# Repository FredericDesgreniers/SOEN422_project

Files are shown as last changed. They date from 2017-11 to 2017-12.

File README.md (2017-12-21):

# Force Test - SOEN422 Group Project
Our plan for this project to to build a force test system which is intended to be used for boxers/kickboxers to gauge the force the hit the bag with; see the [project proposal](#https://github.com/FredericDesgreniers/SOEN422_project/blob/master/Docs/Proposal.md) for more details.

### Table of Contents
1. [Contributors](#Contributors)

## Contributors - Team A
**Name** | **ID**
:--:|---
Christopher McArthur | `40004257`
Frederic Desgreniers | `40016777`

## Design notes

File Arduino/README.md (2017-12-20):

# Arduino

## Attributions
* [HX711 Library](https://github.com/bogde/HX711)
* [HX711 Tutorial](http://www.instructables.com/id/How-to-Interface-HX711-Balance-Module-With-Load-Ce/) // using same model
* [Complete Guide](https://circuits4you.com/2016/11/25/hx711-arduino-load-cell/) // using same model
* [Loadcell Technical Information](https://www.phidgets.com/docs/Load_Cell_Primer#Single-Point_Load_Cells)
* [How to wire four wheatestone bridge load sensors](https://electronics.stackexchange.com/questions/111887/load-cells-in-series)
* [HX711 datasheet](https://www.mouser.com/ds/2/813/hx711_english-1022875.pdf)

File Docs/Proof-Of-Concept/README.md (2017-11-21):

# Proof of Concept - Team Cerberus
In this stage of the project we set out to build a small test setup using the hardware obtained. This would allow us to build the Web UI and communication components congruently with the engineering of the full scale device and proide the necessary knowledge to build a full system.

> To best view this document, use the [link](https://github.com/FredericDesgreniers/SOEN422_project/blob/master/Docs/Proof-Of-Concept/README.md) provided.

### Table of Contents
1. [Contributors](#Contributors)
2. [Test Unit](#test-unit)
3. [Results](#results)
4. [Future Rquirements](#Future-Rquirements)
5. [Figures](#Figures)

## Contributors
**Name** | **ID**
:--:|---
Christopher McArthur | `40004257`
Frederic Desgreniers | `40016777`

## Test Unit
Using the Arduino Nano Rev3, an HX711 and a 10kg load cell we built a small scale to prove that we can be able to register the force applied to the strain gauge. See [figure 1](#figure-1) for reference. Determining how to correctly wire the load cell to the HX711 and connecting that to the Arduino possed several challenges as some resources used different wire layouts. The diagram below shows the correct layout: 

## Results
Using the [HX711 Library](https://github.com/bogde/HX711) and some sample code provided for the HX711 by [SparkFun](https://learn.sparkfun.com/tutorials/load-cell-amplifier-hx711-breakout-hookup-guide) we were able to successfully calibrate the scale to accurately weigh a 3 and 10 pouns weights.

## Future Rquirements
* [Combinator Board](http://www.robotshop.com/ca/en/load-sensor-combinator-v11.html)
* [50kg Load Cell](http://www.robotshop.com/ca/en/micro-load-cell-50-kg.html) X4 (Seriouly four)

The goal is to measure the force delivered with a punch (by a retired amature kickboxer). In order to do this we need to have load cells which will be able to capture that quantity of force. We have settled for 4 x 50kg load cells giving a total of 440lbs. These will make the engineering more simple compared to using other types of strain gauges. The proposed design will feature two circular plates that will be bolts to the load cells. The top plate will be half the diameter of the bottom plate. The direction of the load cells will be places in the center to register the force applied to the top plate. See [figure 2](#figure-2) and [figure 2](#figure-2) for a visual. The 4 x 50kg load cells will be connected with a combinator board which is required to have all four work as one which will then be connected to the HX711 and the Nano.

## Figures

### Figure 1


### Figure 2


### Figure 3


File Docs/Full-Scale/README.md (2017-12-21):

# Force Gauge - Team A
In this project we aimed to develop a force gauge which was capable of detecting the force applied from a human punch. This document outlines the goals of the project, the design of the system, and the final resulting prototype which was delivered.

> To best view this document, use this [link](https://github.com/FredericDesgreniers/SOEN422_project/blob/master/Docs/Full-Scale/README.md).

### Table of Contents
1. [Contributors](#contributors)
1. [Introduction](##force-gauge---team-a)
1. [Description](#description)
   1. [Name](#name)
   1. [Functionality](#functionality)
   1. [Performance](#performance)
   1. [Scope of Completion](#scope-of-completion)
1. [Hardware Design](#hardware-design)
   1. [System](#system)
   1. [Subsystems](#subsystems)
   1. [Intercommunication](#intercommunication)
1. [Software Design](#software-design)
   1. [System Design](#system-design)
   1. [Subsystems](#subsystems)
      1. [Arduino Functions](#arduino)
      1. [BeagleBone Functions](#beaglebone)
      1. [External Functions](#Web-Server)
   1. [System Software Communication](#system-software-communication)
1. [Development Software and Enviroments](#development-software)
1. [System Delivery](#system-delivery)
   1. [Initialisation](#system-initialisation)
   1. [Operation](#system-operation)
1. [Discussion](#discussion)
1. [Apendix](#apendix)

## Contributors
**Name** | **ID**
:--:|---
Christopher McArthur | `40004257`
Frederic Desgreniers | `40016777`

## Description
#### Name
This force gague system, called the **Punch O-Meter**, is designed to be placed into any punching bag and display live results of the forces being applied.

#### Functionality
The system would include a web server and with an internet connection allowing users to view the data from their computer or mobile device. This data is the _force_ currently applied to the bag which is being captured by a microcontroller of the force gauge(s) set up in the bag. 

#### Performance
It is designed to capture the force from various types of punchs, meaning it is responsive enough to capture a quick double jab and strong enough to handle a left hook. Users are able to display the force in pounds, kilos, or newtons and track sessions to see the greatest force applied during their training.

#### Scope of Completion
The project succeded is producing a functional prototype which was able to capture the force applied and displayed the results through a web interface. However the lantency of the system was never refined to be low enough to capture a punch reliably. In addition the force gauge did experience some deformation under strong impacts, see [Figure 5](#figure-5), thought this did not degrade accuracy.

## Hardware Design
#### System
The system is comprised of three components; a force gauge, an arduino microcontroller, and a beaglebone black. Together they registered, interpolated and presented the data to provide a smooth user experience. Additionally an external machine was used to run the webserver to allow for better connectivity. An example of the system can seen in [Figure 4](#figure-4) and the diagram in [Figure 6](#figure-6).

#### Subsystems
###### Force Gauge
The main hardware component is the force gauge itself, this went through many phases thought stuck with the initial concept of usign fource loadcells to mesure the weight (ie force) being applied. The first step was a proof of concept model, see [Figure 1](#figure-1), which used a single loadcell as a scale and printed the weight. The loadcell was a wheatestone bridge type which was connected to an HX711; a specialized amplifer for these types of loadcells. The output of the HX711 was digital and made it easily captured by an Arduino Nano which used serial (UART) communication to desplay the results on a monitor.

The concept model, see [Figure 2](#figure-2), was two circular plates with the four loadcells in between positioned an equal distance for the center and aligned at 90 degrees. This layout was changed early on in the development of the full scale model for serval factors:
- Calculating the geometry of the system was more complex
- Limitations in supply/availibilty of material (turn rectangles into circles)

For these reasons we opted for two rectangular plates; the top plate is `3x4x1/4` and the bottom plate is `5x4x1/4`. The top plate is centered over the bottom plate with an inch margin on the left and right sides of the force gauge. The top plate is smaller to provide a concentrate area to deliver the force as well as the requirements of the loadcell's placement.

###### HX711
This is the hardware which connects the force gauge to the arduino. it works by output a 5V to the loadcell and using the return voltage it calculates the resistence using an ADC, analog to digital conversion, which is translated to the weight in grams being stored on a 24-bit register. When the HX711 recieves a `HIGH` signal it performs a digital write of the next bit to be read.

###### Microcontrollers
**Arduino**'s role was to read and compute the data outputed from the force gauge through the amplifier. Reading the digital output it would convert this using offsets and scaling to determine the number of pounds which it would then output.

**BeagleBone**'s role was read the output from the arduino and forward the information to the web application using the network connection.

#### Intercommunication
**Force Gauge** --> **Arduino**: Wheatestone bridge senors like our load cells procude an analog output, this is passed though an amplifier, namely our HX711, which is designed to convert our analog output to a digital input for the arduino. In order to read all four load through one input of the HX711, the load cells were wired in parellel.

**Arduino** --> **BeagleBone**: In order to get the data onto the web server, we needed a network connection. Our arduino forwarded all the data through a UART communication with the beaglebone.

**BeagleBone** --> **Web Server**: Using it's network connection the BeagleBone would open a web socket with the web application and using HTTP post method is would tranmit the data would could then be added to the graph.

## Software Design
#### System Design
The software was responsible for transfering the values outputed by the scale from the arduino to the beaglebone and finalyl to the webserver. 

**Arduino**: a c++ program read the output data from the force gauge and forward the information to the beaglebone.

**BeagleBone**: a python program was used in order to bridge communication between the arduino and the web server used to render a chart of the force applied.

**Web Application**: Store a small history of the data points and display them on a graph showing the user the results of each impact.

#### Subsystems
###### Arduino
There are two main C++ applications used on the Arduino. The first is the calibration sketch which allows for the calculation of this calibration factor. The HX711 and its adjacent [library](https://github.com/bogde/HX711) output a digital value in grams, however this is not always true depending on the scale. In our case we wanted to use pounds as our units, as such we placed various weights on our scale and adjusted the `calibration_factor` until all the weight's were properly reported, see [Figure 4](#figure-4). The main application, in other words the one used for the system, uses the calculated `calibration_factor` and serial writes the data.

The key behind this is the [library](https://github.com/bogde/HX711) being utilized. The main application (using arduino for the UART) is as follows:
```C++
#include "HX711.h"

HX711 scale(PD6, PD7);

void setup() {
   Serial.begin(9600);
   scale.set_scale(-6500);
   scale.tare();
}

void loop() {
   Serial.println(scale.get_units(), 4);
}
```
Beginning with the instantiation of the `scale` we pass two pins; _DOUT_ or "Data OUTput" and _SCK_ or "Synchronized ClocK". Both pins have thier pin modes set to input and output respectively. Next we set our calibration factor but using `scale.set_scale(-6500)` which holds the value in a private member of the object and is used when `scale.get_units()` to convert the value read to our scale. With the scaling configured, we now call `scale.tare()` to remove the weigth of the top plates and any tension the system might be under. This tare method works by reading 10 values and calculating the average and once again sotring the value in a private member of the object. Within our loop our one and only HX711 library call is `scale.get_units()` which returns a float being the weight on the force gauge maped to out unit of choice. Behind the scene of the library, used by both `tare()` and `get_units()` is the `read()` functions which is the heart of the library because it is reponsible for exacting the values from the HX711 amplifier. The following snippet is the read function of the library.
```c++
long HX711::read() {
   // wait for the chip to become ready
   while (!is_ready()) { // bool HX711::is_ready() { return digitalRead(DOUT) == LOW; }
      // Will do nothing on Arduino but prevent resets of ESP8266 (Watchdog Issue)
      yield();
   }

   unsigned long value = 0;
   uint8_t data[3] = { 0 };
   uint8_t filler = 0x00;

   // pulse the clock pin 24 times to read the data
   data[2] = shiftIn(DOUT, PD_SCK, MSBFIRST);
   data[1] = shiftIn(DOUT, PD_SCK, MSBFIRST);
   data[0] = shiftIn(DOUT, PD_SCK, MSBFIRST);

   // set the channel and the gain factor for the next reading using the clock pin
   for (unsigned int i = 0; i < GAIN; i++) {
      digitalWrite(PD_SCK, HIGH);
      digitalWrite(PD_SCK, LOW);
   }

   // Replicate the most significant bit to pad out a 32-bit signed integer
   if (data[2] & 0x80) {
      filler = 0xFF;
   }
   else {
      filler = 0x00;
   }

   // Construct a 32-bit signed integer
   value = (static_cast<unsigned long>(filler) << 24
      | static_cast<unsigned long>(data[2]) << 16
      | static_cast<unsigned long>(data[1]) << 8
      | static_cast<unsigned long>(data[0]));

   return static_cast<long>(value);
}
```
At first glance, the code looks complex, but with a little bit of reading the HX711 datasheet and research of arduino functions is makes sense. The method begins by waiting for the HX711 to be free, in other words for no one else to be reading, though in our case that is not an issue. Following this the function extracts the 24bits of data from the HX711's register, see the [HX711 hardware](#HX711) section for details, and stores it on a buffer. The gain, the channel and percision selection, is reset. And lastly the 24-bit value is translated to a 32-bit variable.

###### Beaglebone
A python script was used to bridge the communication between the arduino and the java web server. The script used a library called PySerial. 
```python
import serial
import requests

ser = serial.Serial('/dev/ttyO2', 9600)

while True:
   dataValue = ser.readline()
   requests.post('http://192.168.7.1/data', data = dataValue)
   
ser.close() 
```

The `serial.Serial('/dev/ttyO2',9600)`call opens the uart2 port (ttyO2) for communication with a baudrate of 9600. `PySerial` itself [will call `os.open()`](https://github.com/pyserial/pyserial/blob/92d101613be41ecb2f2054c3f43a006fbe6f9966/serial/serialposix.py#L265) using the port name which will return a file descriptor, which in this case is a handle to the port. 

[`ser.readline()` from `io::IoBase`](https://docs.python.org/2/library/io.html#io.IOBase.readline) is a standard python method that reads a stream by calling the `IoBase::read()` method until a new line is found. 

The `read()` method is [overriden by `PySerial`](https://github.com/pyserial/pyserial/blob/92d101613be41ecb2f2054c3f43a006fbe6f9966/serial/serialposix.py#L471). The posix version of the `PySerial` code will then call python's `select.select()` method, which [translates to a `select()` system call on linux](https://docs.python.org/2/library/select.html#select.select). This will wait until the port is ready to read and then calls `os.read()` on the serial port to read the data comming from the uart connection. 

`requests.post(..)` is part of the standard python libraries and makes a standard http post request the local java server. 

###### Web Server
A java webserver using the Spring Boot framework is responsible for displaying the values sent by the python server on a web page. 
The webpage uses a chart library (CanvasJS) and websockets in order to constantly update the values. 

The spring boot application enables websocets using `@EnableWebSocketMessageBroker` on the main config class. 

It then registers a web socket entry point using
```java
@Override
public void configureMessageBroker(MessageBrokerRegistry config) {
    config.enableSimpleBroker("/data");
    ...
}
```
That makes it so a client can connect to a websocket using /data/sub.

This can be seen in the javascript code:
```javascript
stompClient.subscribe('/data/sub', function (message){
    var dataToShow = JSON.parse(message.body);
    dps.push({
        x: dataToShow.time,
        y: dataToShow.force
    });
    if (dps.length > dataLength) {
        dps.shift();
    }
    chart.render();
});
```
It subscribes to /data/sub and then pushes a new value to the chart every time a message gets received. 
Every time a value is sent to /data using POST, this method gets triggered: 
```java
@RequestMapping("/data")
public ResponseEntity<String> data(@RequestBody String body) {

    template.convertAndSend("/data/sub", new DataMessage(index.getAndIncrement(), Float.valueOf(body)));

    return ResponseEntity.status(200).build();
}
```

Since only the value is sent in the POST request body, we can convert it directly to a float using `float.valueOf(body)`. 
`template.convertAndSend(...)` will send a websocket message made of an index integer and a float to all the subscribers of the /data/sub websocket. 

#### System Software Communication
The amplifier outputs in serial which means the arduino can do a serial read using serial pins. The arduino will then send the number as a string of characters and a new line to the beaglebone using UART (TX/RX pins on both) which nis read by a python script. The beaglebone will take the values and send them over the local network to the computer running the java web server. The connection from the beaglebone to the computer / webserver is done over usb network sharing. The web server will then use the network to send websockets to the clients. 

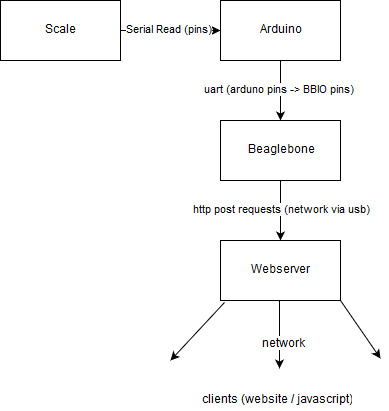
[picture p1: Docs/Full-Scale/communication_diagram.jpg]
communication diagram image


## Development Software
#### Arduino
- The arduino programs were written in Visual Studio (Enterprise 2017)
- Visual Micro was used to link visual studio to the arduino compilers, linkers, loaders, etc.
- Arduino IDE was installed for all the tools and drivers required

#### Beaglebone
- Vim / Nano was used for coding and editing configuration files on the beaglebone. Both were are installed by default with the linux distribution. 
- Cape manager waas used to add the UART overlay. Installed by default.
- Python was used for scriping. `PySerial` was downloaded using python's pip command, also installed by default. 

#### External
- Java was used to run the webserver.
- Intellij was used for creating the java web server along with maven for dependency management and packaging. 
- Maven dependencies we're all from the spring-boot framework. 
- Putty and Ubunutu subsystem for windows were used to shh into the beaglebone.

## System Delivery
#### System Initialisation 
###### Arduino
Flash the main force gauge sketch to the arduio.

###### Beaglebone
**Shell**: `sudo gateway default add 192.168.7.1` and `echo "nameserver 8.8.8.8" > etc/resolv.conf` will enable the beaglebone to use the external computers internet connection. 

**Python**: `sudo pip install PySerial` will install the dependency required for uart communication.

**UART**: In userspace run `sudo sh -c "echo UART2 > /sys/devices/platform/bone_capemgr/slots"` which will add the uart2 tree overlay

###### Windows Computer
**Network**: Enable internet sharing on the proper network adapter (the one connected to the internet). 

**Web Server**: Install a java 8+ jdk [like the oracle one](http://www.oracle.com/technetwork/java/javase/downloads/jdk9-downloads-3848520.html). Another option is [openjdk](http://openjdk.java.net/install/index.html).
Install [apache maven](https://maven.apache.org/). In the /website source code directory, run `mvnw clean`, `mvnw validate` and `mvnw package`. This will create a jar in the /target directory that can be run. 

To deploy the web application, in no particular order, start the java server using `java -jar {jar-name}` where the jar name is the jar found in the /target directory and plug in the arduino to the beaglebones power, ground and appropriate uart pins.

Once that is setup, turn on the beaglebone and run the python script by calling `python driver.py`. Once this is done, opening http://127.0.0.1:8080 on the computer/web server should create a webpage with a graph. 

#### System Operation
Once everything is initialized and plugged in, no further interaction is required besides opening the web page previously mentioned. Values should appear on the graph as soon as weight is applied to the scale. 

## Discussion
This section expands on work done which is not present in the final prototype or is not covered in the precedding sections of the report.

###### Internet - Wifi setup
We initially connected it using an ethernet cable, however, this method stopped working at one point for no apparent reason so we had to switch to using the usb connection for internet access. 

While the internet should be very straightforward to enable on the beaglebone using usb, we had problems making it work due to both windows not working properly and not having DHCP. This was fixed by manually adding the network gateway to the beaglebone, manually adding the ip address and re-installing network drivers on the windows machine. 

###### Choosing language
For the arduino part, we used c++ without much other consideration since it allows easy access to both low level memory and aduino specific functions.

For the beaglebone, the chocie was mostly between c++, python and java. Python was chosen because it had the most easy to use and mature libraries for communication. Java was chosen for the webserver since it initially looked like a decent idea to use a mature web framework such as spring boot. This ended up being a bad decision since using java on the arduino took up a lot of memory. Spring is also a very bloated framework that includes a lot of unncessary things. In the end, c++ would have been the better choice because it's lightweight and the functions we needed out of the webserver would have been straightforward to implement (http page + websockets). 

###### Force Gauge Engineering
This main component went through may phases from a prototype, model to a first attempt. The leading factors which transformed the designed from [Figure 2](#figure-2) to the working model in [Figure 3](#figure-3) was the geometery and avaliable reasources. Calculating the best positions and aligning the loadcells becames far to complex so the design was switch to using squares. However at this point the diamond plate which I had was preventing the bolts from sitting correctly. The aluminum plate I had on hand was `8x4` so the final product was a rectanglar.

The bolts for the loadcells were supposed to be inset to the plate so they would no be pretruding. This did not come to fruition because the bolts I aquired were made to sit flush. This later on came to haunt us. When calibrating the system and going through some initial tests, I through a straight right and my large knuckle made full contact with the bolt head. This meant that a single loadcell was under the strain of a approxiamtely 180lbs punch. The result of the impact was the thin bolt bending that skewing the geometry of the force gauge distorting the results slightly.

###### Wiring
There are many examples of IoT scales online which use four load cells as our design. These project often used a load cell combinator board which connected four loadcells into one wheatestone bridge circuit. Unfortunelty there was not enough research done to determine in advance that the combinator board was not for the type of loadcells which we had aquired for this project. This meant the senors needed to be wired in such a away that the four wheatestone bridge ciruits worked together to produce one uniformed output which could be utilised by out HX711. I took two days of research to finally dig up the answer in some obsure stack overflow for electrical engineering which referenced a technical paper on the subject. Plugging in the wires took all of one minute.

The main problem with the beaglebone's wiring was figuring out how to enable the proper pins and which pins we needed to connect wires too. The problem was fixed when we switched from spi to uart since the ports were clearly identified. We also had trouble because the cape_universal overlay disabled the uart pins, this was fixed by removing the overlay from the cape manager configuration. 

A smaller issue which came up because of the wiring was the gauge of the wires which came with the load cells. In order to have a proper connection inside a breadbord pin, the wire must be thick enough to make contact with the side wall. However the wire of the loadcells were were thin and we needed to soder thinker extension wires onto the ends of the 16 wires.

###### Calibrating the Force Gause
Our initial proof of concept used a 10kg load cell; the calibration was very easy using a 3lbs and a 10lbs weight. When scaling up to a 200kg scale, calibrating the system required heavier wieghts as the force gauge is less sensitive at lower and upper range. This means the effective range is from 5kg to 190kg. In order to have a good calibration factor I used a 20kg plate, myself and myself holding a bar with two plates. Standing on one foot on a `3x4` inch square with 135lbs on you was not easy. This difficult was a direct result of stupidity and easily could of been avoided.

###### Web server + application
The python program was meant to send the values using an http POST request to a java webserver, also hosted on the beaglebone. However, the server ended up being hosted an external computer due to a faillure to get newer versions of java working on the beaglebone. 

The library used for websockets is java 8+, however the beaglebone defaults to java 7 when installing using the normal methods. At the time we found out about it, it was too late to change the functionality in order to support java 7. We tried installing java 8 or 9 on the beaglebone but had problems due to what seemed like an incompatible kernel. 

We also had a problem with space management on the beaglebone since their wasn't enough space for the python libraries, the source code, java and all the java dependencies. This was mostly due to a faillure when selecting the web framework since spring-boot is far from lightweight. Looking back, using a handmade c++ or python webserver would have been a better solution. 

## Apendix

#### References
* [PySerial Library](https://github.com/pyserial/pyserial)
* [HX711 Library](https://github.com/bogde/HX711)
* [Spring Boot Library](https://github.com/spring-projects/spring-boot)

#### Figures
###### Figure 1
proto type
###### Figure 2
concept modle
###### Figure 3
system
###### Figure 4
calibration
###### Figure 5
deformation
###### Figure 6


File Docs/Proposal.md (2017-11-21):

# Project Proposal

### Table of Contents
1. [Contributors](#Contributors)
2. [Concept](#Concept)
3. [Systems](#Systems)
4. [Extra Hardware Requirements](#Extra-Hardware-Requirements)

## Contributors - Team Cerberus
**Name** | **ID**
:--:|---
Christopher McArthur | `40004257`
Frederic Desgreniers | `40016777`

## Concept
Having spent several years as an amature kickboxer, one question that has always came up in the gym is

> How much force am I hitting with?

The challenge with this is that technical skills required for building the correct test gauge are not common in the community nor are the funds to by fancy equipement. That however is longer not the case. When I was a teenager there was a show sports science which done [episodes](https://www.youtube.com/watch?v=-iLno2uSRXg) of this and fulled my curiosity. The basic idea because this will be to build a system which will be able to accurately detect the force applied from a punch or kick and display it on a monitor. I specialize in network applications so I would be most comftorable using my costume IP for the communication between the Arduino and Begalbone. In line with this would most likely be a web UI for view the results of each test.

## Systems
I would like to build two systems, though in-depth design will be needed to establish which is less fesable.

- Boxing: _Force plate_ - This will be a flat plate for test subjects to punch and will work much like a scale. The difficulty will lie in the engineering of the device. It will be required to hang vertiacally making it difficult to use many of the cheaper types of load cells as attaching the front plate correctly becomes a concern.
- Kickboxing: _Bag gauge_ - This would eliminat much of the engineering difficults of mounting the load cells but would require a higher rated cell because the force behind a pick is much greater. The biggest difficulty will be place the device correctly to capture the force without it being diminised by the bag swing.

## Extra Hardware Requirements
* [HX711](https://www.sparkfun.com/products/13879) < $10
* 4 x [Load Cell 50kg](http://www.robotshop.com/ca/en/micro-load-cell-50-kg.html) < $10 each
* [Combinator Board](https://www.sparkfun.com/products/13878) < 2$
* Wifi dongle for the Begalbone Black

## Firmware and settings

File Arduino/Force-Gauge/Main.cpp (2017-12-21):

/*
MIT License

Copyright (c) 2017 Frederic Desgreniers, Christopher McArthur

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
THE SOFTWARE IS PROVIDED "AS IS", WITHOUT WARRANTY OF ANY KIND, EXPRESS OR
IMPLIED, INCLUDING BUT NOT LIMITED TO THE WARRANTIES OF MERCHANTABILITY,
FITNESS FOR A PARTICULAR PURPOSE AND NONINFRINGEMENT. IN NO EVENT SHALL THE
AUTHORS OR COPYRIGHT HOLDERS BE LIABLE FOR ANY CLAIM, DAMAGES OR OTHER
LIABILITY, WHETHER IN AN ACTION OF CONTRACT, TORT OR OTHERWISE, ARISING FROM,
OUT OF OR IN CONNECTION WITH THE SOFTWARE OR THE USE OR OTHER DEALINGS IN THE
SOFTWARE.
*/

#include "HX711.h"
#define BAUD 9600
#include <util/setbaud.h>
#include <avr/io.h>

void Serial_init();
void Serial_println(const char* s);

int main()
{
   HX711 scale(PD6, PD7);
   scale.set_scale(-6500);
   scale.tare();

   Serial_init();

   for (;;)
   {
      float retval = scale.get_units();
      char buffer[16];

      dtostrf(retval, -14, 4, buffer); // AVR float to char* conversion

      Serial_println(buffer);
   }
}

// UART FUNCTIONS -------------------------------

void Serial_init()
{
   UBRR0H = UBRRH_VALUE;
   UBRR0L = UBRRL_VALUE;

#if USE_2X
   UCSR0A |= _BV(U2X0);
#else
   UCSR0A &= ~(_BV(U2X0));
#endif

   UCSR0C = _BV(UCSZ01) | _BV(UCSZ00);
   UCSR0B = _BV(RXEN0) | _BV(TXEN0);
}

void Serial_write(char c)
{
   loop_until_bit_is_set(UCSR0A, UDRE0);
   UDR0 = c;
}

void Serial_println(const char* s)
{
   while (*s)
   {
      if(*s == ' ') break; // stop once a whitespace is hit
      Serial_write(*s);
      s++;
   }
   Serial_write('\n');
}

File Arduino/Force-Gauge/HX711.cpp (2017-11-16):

#include <Arduino.h>
#include "HX711.h"

#if ARDUINO_VERSION <= 106
// "yield" is not implemented as noop in older Arduino Core releases, so let's define it.
// See also: https://stackoverflow.com/questions/34497758/what-is-the-secret-of-the-arduino-yieldfunction/34498165#34498165
void yield(void) {};
#endif

HX711::HX711(byte dout, byte pd_sck, byte gain) {
   begin(dout, pd_sck, gain);
}

HX711::HX711() {
}

HX711::~HX711() {
}

void HX711::begin(byte dout, byte pd_sck, byte gain) {
   PD_SCK = pd_sck;
   DOUT = dout;

   pinMode(PD_SCK, OUTPUT);
   pinMode(DOUT, INPUT);

   set_gain(gain);
}

bool HX711::is_ready() {
   return digitalRead(DOUT) == LOW;
}

void HX711::set_gain(byte gain) {
   switch (gain) {
   case 128:		// channel A, gain factor 128
      GAIN = 1;
      break;
   case 64:		// channel A, gain factor 64
      GAIN = 3;
      break;
   case 32:		// channel B, gain factor 32
      GAIN = 2;
      break;
   }

   digitalWrite(PD_SCK, LOW);
   read();
}

long HX711::read() {
   // wait for the chip to become ready
   while (!is_ready()) {
      // Will do nothing on Arduino but prevent resets of ESP8266 (Watchdog Issue)
      yield();
   }

   unsigned long value = 0;
   uint8_t data[3] = { 0 };
   uint8_t filler = 0x00;

   // pulse the clock pin 24 times to read the data
   data[2] = shiftIn(DOUT, PD_SCK, MSBFIRST);
   data[1] = shiftIn(DOUT, PD_SCK, MSBFIRST);
   data[0] = shiftIn(DOUT, PD_SCK, MSBFIRST);

   // set the channel and the gain factor for the next reading using the clock pin
   for (unsigned int i = 0; i < GAIN; i++) {
      digitalWrite(PD_SCK, HIGH);
      digitalWrite(PD_SCK, LOW);
   }

   // Replicate the most significant bit to pad out a 32-bit signed integer
   if (data[2] & 0x80) {
      filler = 0xFF;
   }
   else {
      filler = 0x00;
   }

   // Construct a 32-bit signed integer
   value = (static_cast<unsigned long>(filler) << 24
      | static_cast<unsigned long>(data[2]) << 16
      | static_cast<unsigned long>(data[1]) << 8
      | static_cast<unsigned long>(data[0]));

   return static_cast<long>(value);
}

long HX711::read_average(byte times) {
   long sum = 0;
   for (byte i = 0; i < times; i++) {
      sum += read();
      yield();
   }
   return sum / times;
}

double HX711::get_value(byte times) {
   return read_average(times) - OFFSET;
}

float HX711::get_units(byte times) {
   return get_value(times) / SCALE;
}

void HX711::tare(byte times) {
   double sum = read_average(times);
   set_offset(sum);
}

void HX711::set_scale(float scale) {
   SCALE = scale;
}

float HX711::get_scale() {
   return SCALE;
}

void HX711::set_offset(long offset) {
   OFFSET = offset;
}

long HX711::get_offset() {
   return OFFSET;
}

void HX711::power_down() {
   digitalWrite(PD_SCK, LOW);
   digitalWrite(PD_SCK, HIGH);
}

void HX711::power_up() {
   digitalWrite(PD_SCK, LOW);
}

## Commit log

2017-11-16 correcting proj settings + adding HX711 lib
    [HX711-Test.ino, HX711.cpp]
2017-11-16 use calibration to find 0
2017-11-16 changed test program to read with calc'd calibration factor
2017-11-17 Adding 3D render of force gauge device
2017-11-20 set to calibration code
2017-11-20 correcting pin values
2017-11-20 quick wiring ref
2017-11-20 calc'd calibration factor
2017-11-20 Adding basic outline of POC section
    [breadboard.fzz]
2017-11-23 adding comb board hookup link
2017-11-23 rm picture
    see POC for a fritzing wire diagram
2017-11-23 adding details for top bolt in full scale design
2017-12-02 Added boardcasting of data packets to web page and updating of chart
2017-12-14 adding link for load cell wiring
2017-12-15 changed to calibration sketch
2017-12-15 using proper calibration factor
2017-12-19 Fixed the links in the table of contents to properly link and added an image
    They should be lower case
2017-12-20 seperating/new calibration + force gauge vcxproj
2017-12-20 adding details for hx711 hardware and arduino software
2017-12-20 fillled in arduino section of Development Software
    changed the formating
2017-12-20 Small bit on beaglebone wires
2017-12-20 adding System.fzz to full scale docs
    [System.fzz]
2017-12-21 adding bare metal code for UART in force gauge vcxproj
